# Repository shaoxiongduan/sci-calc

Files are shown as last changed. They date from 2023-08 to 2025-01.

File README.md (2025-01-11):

# sci-calc
<a href="https://github.com/shaoxiongduan/sci-calc/">
Repo Banner - Awesome Repo Template</a>

<p align="center">
  <b>SCI-CALC: A Multifunctional Scientific Calculator</b>

  <br>
    
  <a href="https://github.com/shaoxiongduan/sci-calc/fork">
    
  </a>
  
  <a href = "https://discord.gg/ZbaYb36wnn">

  </a>
</p> 

## Overview

The sci-calc (I know, really creative name) is a 4-in-1 device, packing a scientific calculator, a macropad/numpad, a handheld game console, and a development board all into one neat and sleek little device.

## Specs
- Powered by an ESP32 WROOM32 E [datasheet](www.espressif.com/sites/default/files/documentation/esp32-wroom-32e_esp32-wroom-32ue_datasheet_en.pdf)
- Switches: kailh v1 choc switches
- Screen: 256x64 monochrome oled (display driver: SSD1322)
- Usb to serial chip: CH340C [driver download](learn.sparkfun.com/tutorials/how-to-install-ch340-drivers/all)
- Battery: any lipo battery under 1000mah would be fine
- SD card support (must be in FAT32 format)

## Function Keys
- Switch layer key: switches between different layout configurations
  - hold to switch to next layer, release to go back (like shift)
  - double press to switch to next layer and lock (like caps lock)
- deg/rad: used in the calculator program to switch between degree mode and radian mode
- tab: also used in the calculator program, it's used to switch between the input box and the list of previous calculations
## UI
### Calculator
A calculator with a history clipboard that can do basic arithmetic (add, subtract, multiply, divide, powers), as well as trigonmetric functions, natural logrithms and exponents. Equation solver and derivative calculator will come soon.

when inputting expressions, switch layer is needed to move the cursor left or right, whereas in the history menu(and all of the other menus), holding switch layer is not necessary to use the arrow keys.
when in the history menu, use the arrow keys to navigate up/down, and press enter to copy the selected expression's answer to the input box.

[Video Demo (Outdated)](https://user-images.githubusercontent.com/46639847/219936733-cb611f87-4cae-4c7e-8eed-b2f6bcc909a7.mp4)

### Macropad

A bluetooth numpad that comes with 10 customizable macro keys, though all keys can be customized, only the 10 keys on the 2 rightmost rows can be displayed on the screen.
Macros and layers are very easy to create in code (see firmware), and I'm planning to make it possible to change and edit the layout via a text file in the SD card.

[Video Demo (Outdated)](https://user-images.githubusercontent.com/46639847/219937053-a5f0e39d-01d1-4069-9902-0d509ead685e.mp4)

### Programs

It is possible to upload your own code to the sci-calc by copying the .bin file that you compiled onto the SD card and creating a menu link to it in the main firmware code (see firmware), but this is kinda complicated and I'm trying to make it automatically create the link.
It's pretty easy to port code over to the sci-calc, just copy the Util.h, Util.cpp, Keyboard.h, Keyboard.cpp files over to your project and change the input checking functions.
Currently I've ported littlerookchess, spacetrash, snake, and tetris to it.

[Game Demo](docs/game_demo.md)

## Assembly Guide
[link](https://youtu.be/RY_riS_9hHA?si=YKYpsfk6U_JUeETe)

# Layouts

[Layouts](docs/layout.md)

# Troubleshooting
[Troubleshooting](docs/troubleshooting.md)

# Updating Software
[Updating Software](docs/updating_software.md)

# Setting up the Dev Environment
[Environment Setup](docs/environment_setup.md)

# Code Structure
[Code Structure and Walkthrough](docs/code_structure.md)

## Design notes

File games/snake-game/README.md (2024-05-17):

# Snake Game
Snake game running on esp32, displayed on SSD1306 controlled OLED, developed in Arduino.

Input pins can be changed in the main sketch file. It should be easily portable to other displays, just change the `renderer.cpp` and if needed adjust board size in `snake.h` too.

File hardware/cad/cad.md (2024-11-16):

# CAD Files

Full cad files can be viewed in [Onshape](https://cad.onshape.com/documents/948c55b28636babd8c20a62c/w/3db18c0d723d08fe7c6301bf/e/b61d2ec68282ba356d5c1233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)

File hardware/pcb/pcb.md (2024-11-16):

# PCB

The PCB was designed in EasyEDA.

[Link to EasyEDA](https://easyeda.com/editor#id=1234567890)

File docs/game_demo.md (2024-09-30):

# LittleRookChess


https://github.com/olikraus/u8g2/blob/master/sys/arduino/u8g2_page_buffer/LittleRookChess/LittleRookChess.ino
# Spacetrash


https://github.com/olikraus/u8g2/blob/master/sys/arduino/u8g2_page_buffer/SpaceTrash/SpaceTrash.ino
# Snake


https://github.com/norbertg1/Snake-game
# Tetris


https://github.com/Zimoslaw/TetriZimoslaw

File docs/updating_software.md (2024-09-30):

# Updating Software

## How It Works

The SCI-CALC can load external programs through a SD card.
Each time you load a program, the SCI-CALC writes the contents of the corresponding ```.bin``` file to the ESP32's ROM. For instance, when you load up Chess, it overwrites the existing ```main.bin``` in the ROM to ```chess.bin```. When you press esc to go back, The ```main.bin``` from the SD-card is written back into the ROM. This allows us to update programs without having to use an IDE to upload. The idea is to update the ```.bin``` file of the program in the SD-card, and then load it to the ESP32.

## Updating Software (New)
To update the software for your sci-calc, follow these steps:
1. Get the .bin file you want to update from the ```/bin``` folder.
2. Copy that file over to the microSD card, replacing the old .bin file you want to update.
3. Navigate to the settings menu and activate Update from SD.
4. After it is done writing to ROM it should be properly updated!

## Updating Software (Old)
If you do not see the Update From SD option in the settings menu, follow these steps:
1. Get the .bin file you want to update from the ```/bin``` folder from this repo.
2. Copy that file over to the microSD card, replacing the old .bin file you want to update.
3. Navigate to the programs menu and enter any one of them.
4. once the game is loaded press esc to load the updated main.bin file back to the ESP32.
5. After it is done writing to ROM it should be properly updated!

For updating the main software, do these steps with the ```main.bin``` file. Or you can just replace everything in the SD-card with the contents in the ```/bin``` folder.

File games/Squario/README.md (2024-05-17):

# Squario
### 5/25/16 Update:
Mushrooms picked up after becoming big Squario will fill him, up to 5 times  
Added underworld background and flipped the pipes to the ceiling

### 5/22/16 Update:
Added pipes to break up levels, levels get progressively longer  
Every other level has more of an underworld layout now  
Starmen and thunder bolts should only spawn towards the second half of each level  
Every 20 coins you earn an extra life  
Cleaned up hit detection  
Lots of random backend cleanup and other things I already forgot about

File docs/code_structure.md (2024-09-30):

# Code Structure

The source code for the sci-calc is structured as follows

Folders:
```
Animation
Calculator
Macropad
Stopwatch
UIElements
Utils
```
Files:
```
main.cpp/main.h
Sidebar.cpp/Sidebar.h
UIMain.cpp/UIMain.h
```

Now we will go into each part:
## Animation

The animation engine for the SCI-CALC works like this:

When you insert an animation, for instance this one:
```c++
insertAnimation(new Animation(subElements[i], BOUNCE, subElements[i] -> getX(), cnt * 12 + 12, 100));
```

The animation engine inserts the animation into the two pools depending on what you are animating (one for animating UIElements, one for animating variables)

```cpp
// An element might have multiple animations added to it at once, this mapping procedure makes sure that only the latest animation gets animated

void insertAnimation(Animation* animation) {
	if (animation -> getTargetElement() != nullptr) {
		animationsUI[animation -> getTargetElement()] = animation;
	}
	else {
		 nimationsInt[animation -> getTargetVal()] = animation;
	}
}
```

The animation scheduler then manages and updates the animations based on their duration and positions. This is done by calling their respective animation update functions based on their animation types.

See the code for more stuff.

## Calculator

The calculator folder contains all the regular and RPN calculator codes.

```Calculator.cpp/Calculator.h```: The UI Element for the scientific calculator. It wraps up the logic stuff to display the UI.

```Expression.cpp/Expression.h```
```Node.cpp/Node.h```
: This is where the calculations happen. The Expression class handles the tokenizing, tree-building, and evaluating of the expressions. The calculation module first takes in the input string from the Calculator UI's input box, and then parses it into mathematical tokens. It then uses the shunting-yard algorithm to build an abstract syntax tree (AST), which is used to do the actual calculations.

```ExpressionBlock.cpp/ExpressionBlock.h```
This is the UIElement for displaying the expressions in the history menu.

```CalculatorRPN.cpp/CalculatorRPN.h```
```EvaluatorRPN.cpp/EvaluatorRPN.h```
These classes are the UIElement components and the calculation part for the RPN calculator.

The RPN calculator has 5 registers: x, y, z, t, and a store register which is hidden. It supports basic stack manipulation operations like swap (x, y), push, and pop. I mainly referenced the HP RPN calculators and http://www.alcula.com/calculators/rpn/ when coding this.

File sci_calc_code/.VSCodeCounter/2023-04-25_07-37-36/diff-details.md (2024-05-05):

# Diff Details

Date : 2023-04-25 07:37:36

Directory /Users/shao/Documents/PlatformIO/Projects/230113-120228-esp32doit-devkit-v1

Total : 0 files,  0 codes, 0 comments, 0 blanks, all 0 lines

[Summary](results.md) / [Details](details.md) / [Diff Summary](diff.md) / Diff Details

## Files
| filename | language | code | comment | blank | total |
| :--- | :--- | ---: | ---: | ---: | ---: |

[Summary](results.md) / [Details](details.md) / [Diff Summary](diff.md) / Diff Details

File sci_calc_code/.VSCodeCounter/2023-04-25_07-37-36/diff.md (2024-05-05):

# Diff Summary

Date : 2023-04-25 07:37:36

Directory /Users/shao/Documents/PlatformIO/Projects/230113-120228-esp32doit-devkit-v1

Total : 0 files,  0 codes, 0 comments, 0 blanks, all 0 lines

[Summary](results.md) / [Details](details.md) / Diff Summary / [Diff Details](diff-details.md)

## Languages
| language | files | code | comment | blank | total |
| :--- | ---: | ---: | ---: | ---: | ---: |

## Directories
| path | files | code | comment | blank | total |
| :--- | ---: | ---: | ---: | ---: | ---: |

[Summary](results.md) / [Details](details.md) / Diff Summary / [Diff Details](diff-details.md)

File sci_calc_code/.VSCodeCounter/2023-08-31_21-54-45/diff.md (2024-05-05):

# Diff Summary

Date : 2023-08-31 21:54:45

Directory /Users/shao/Documents/PlatformIO/Projects/230113-120228-esp32doit-devkit-v1

Total : 24 files,  401 codes, 41 comments, 80 blanks, all 522 lines

[Summary](results.md) / [Details](details.md) / Diff Summary / [Diff Details](diff-details.md)

## Languages
| language | files | code | comment | blank | total |
| :--- | ---: | ---: | ---: | ---: | ---: |
| C++ | 23 | 402 | 41 | 81 | 524 |
| Ini | 1 | -1 | 0 | -1 | -2 |

## Directories
| path | files | code | comment | blank | total |
| :--- | ---: | ---: | ---: | ---: | ---: |
| . | 24 | 401 | 41 | 80 | 522 |
| . (Files) | 1 | -1 | 0 | -1 | -2 |
| src | 23 | 402 | 41 | 81 | 524 |

[Summary](results.md) / [Details](details.md) / Diff Summary / [Diff Details](diff-details.md)

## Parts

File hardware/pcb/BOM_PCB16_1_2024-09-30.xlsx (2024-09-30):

No. | Quantity | Comment | Designator | Footprint | Value | Manufacturer Part | Manufacturer | Supplier Part | Supplier
1 | 26 | 2.54-1*1P针 | 5,13,14,15,16,17,18,19,21,22,23,25,26,27,32,33,34,35,36,39,GND,GND,RX,TX,VCC,VCC | HDR-TH_1P-P2.54-V-M |  | 2.54-1*1P针 | BOOMELE(博穆精密) | C81276 | LCSC
2 | 2 | TS-1088-AR02016 | BOOT,EN | SW-SMD_L4.0-W2.9-LS5.0 |  | TS-1088-AR02016 | XUNPU(讯普) | C720477 | LCSC
3 | 2 | 10uF | C1,C6 | C0603 | 10uF | CL10A106KP8NNNC | SAMSUNG(三星) | C19702 | LCSC
4 | 5 | 0.1uF | C2,C4,C5,C7,C8 | C0603 | 0.1uF | CC0603KRX7R9BB104 | YAGEO(国巨) | C14663 | LCSC
5 | 1 | 10uF | C3 | C0805 | 10uF | CL21A106KAYNNNE | SAMSUNG(三星) | C15850 | LCSC
6 | 2 | 22uF | C10,C11 | C0805 | 22uF | CL21A226MAQNNNE | SAMSUNG(三星) | C45783 | LCSC
7 | 1 | TF-01A | CARD1 | TF-SMD_TF-02 |  | TF-01A | Yuandi(台湾元迪) | C2889258 | LCSC
8 | 30 | 1N4148W | D1,D2,D3,D4,D5,D6,D7,D8,D9,D10,D11,D12,D13,D14,D15,D16,D17,D18,D19,D20,D21,D22,D23,D24,D25,D26,D27,D28,D29,D30 | SOD-123F_L2.7-W1.6-LS3.8-RD |  | 1N4148W | ST(先科) | C81598 | LCSC
9 | 1 | SS34 | D32 | DO-214AC_L4.3-W2.7-LS5.3-RD |  | SS34 | MDD | C8678 | LCSC
10 | 1 | TPD4E1U06DCKR | D33 | SC-70-6_L2.2-W1.3-P0.65-LS2.1-BL |  | TPD4E1U06DCKR | TI(德州仪器) | C194628 | LCSC
11 | 1 | 470nH | L2 | IND-SMD_L5.7-W5.4 | 470nH | MHCI05030-R47M-R8 | chilisin(奇力新) | C329374 | LCSC
12 | 2 | 19-217/R6C-AL1M2VY/3T | LED1,PWR | LED0603-R-RD |  | 19-217/R6C-AL1M2VY/3T | EVERLIGHT(台湾亿光) | C72044 | LCSC
13 | 1 | 19-217/GHC-YR1S2/3T | LED2 | LED0603-R-RD |  | 19-217/GHC-YR1S2/3T | EVERLIGHT(台湾亿光) | C72043 | LCSC
14 | 1 | FS8205 | Q1 | SOT-23-6_L2.9-W1.6-P0.95-LS2.8-BR |  | FS8205 | FORTUNE(台湾富晶) | C32254 | LCSC
15 | 1 | AO3401A | Q2 | SOT-23_L2.9-W1.3-P1.90-LS2.4-BR |  | AO3401A | AOS | C15127 | LCSC
16 | 2 | S8050 | Q3,Q4 | SOT-23-3_L2.9-W1.3-P1.90-LS2.4-BR |  | S8050 | 星海 | C2992076 | LCSC
17 | 3 | 1kΩ | R1,R2,R13 | R0603 | 1kΩ | RC0603FR-071KL | YAGEO(国巨) | C22548 | LCSC
18 | 1 | 5kΩ | R3 | R0603 | 5kΩ | AR03BTCX5001 | Viking(光颉) | C2828621 | LCSC
19 | 3 | 100Ω | R4,R10,R11 | R0603 | 100Ω | RC0603FR-07100RL | YAGEO(国巨) | C105588 | LCSC
20 | 1 | 2kΩ | R5 | R0603 | 2kΩ | RC0603FR-072KL | YAGEO(国巨) | C105576 | LCSC
21 | 7 | 10kΩ | R6,R7,R8,R9,R14,R19,R22 | R0603 | 10kΩ | RC0603FR-0710KL | YAGEO(国巨) | C98220 | LCSC
22 | 8 | 10kΩ | R12,R15,R16,R23,R24,R25,R26,R27 | R0603 | 10kΩ | TR0603B10K0P0525Z | EVER OHMS(天二科技) | C188363 | LCSC
23 | 2 | 5.1kΩ | R17,R18 | R0603 | 5.1kΩ | 0603WAF5101T5E | UNI-ROYAL(厚声) | C23186 | LCSC
24 | 1 | 91kΩ | R20 | R0603 | 91kΩ | 0603WAF9102T5E | UNI-ROYAL(厚声) | C23265 | LCSC
25 | 1 | 511kΩ | R21 | R0603 | 511kΩ | 0603WAF5113T5E | UNI-ROYAL(厚声) | C23194 | LCSC
26 | 2 | 100k | R28,R29 | R0603 |  | 100k |  | C9900012835 | LCSC
27 | 30 | CPG135001D01 | SW1,SW2,SW3,SW4,SW5,SW6,SW7,SW8,SW9,SW10,SW11,SW12,SW13,SW14,SW15,SW16,SW17,SW18,SW19,SW20,SW21,SW22,SW23,SW24,SW25,SW26,SW27,SW28,SW29,SW30 | KEY-TH_CPG135001D0X |  | CPG135001D01 | Kailh(凯华) | C400229 | LCSC
28 | 1 | SK12D07VG4 | SW35 | SW-TH_SK12D07VG4 |  | SK12D07VG4 | SHOU HAN(首韩) | C393937 | LCSC
29 | 1 | 4056 | U1 | ESOP-8_L4.9-W3.9-P1.27-LS6.0-BL-EP |  | 4056 | RONGHE(融和) | C392766 | LCSC
30 | 1 | DW01 | U2 | SOT-23-6_L2.9-W1.6-P0.95-LS2.8-BR |  | DW01 | PJSEMI(平晶微) | C686633 | LCSC
31 | 1 | ESP32-WROOM-32E-H4 | U4 | WIFI-SMD_ESP32-WROOM-32E |  | ESP32-WROOM-32E-H4 | ESPRESSIF(乐鑫) | C3013935 | LCSC
32 | 1 | oled | U5 | oled3.1
33 | 1 | CH340C | U6 | SOP-16_L10.0-W3.9-P1.27-LS6.0-BL |  | CH340C | WCH(南京沁恒) | C84681 | LCSC
34 | 1 | TPS63802DLAR | U7 | VSON-10_L3.0-W2.0-P0.50-TL |  | TPS63802DLAR | TI(德州仪器) | C2845237 | LCSC
35 | 1 | TYPE-C-31-M-12 | USBC1 | USB-C_SMD-TYPE-C-31-M-12 |  | TYPE-C-31-M-12 | 韩国韩荣 | C165948 | LCSC

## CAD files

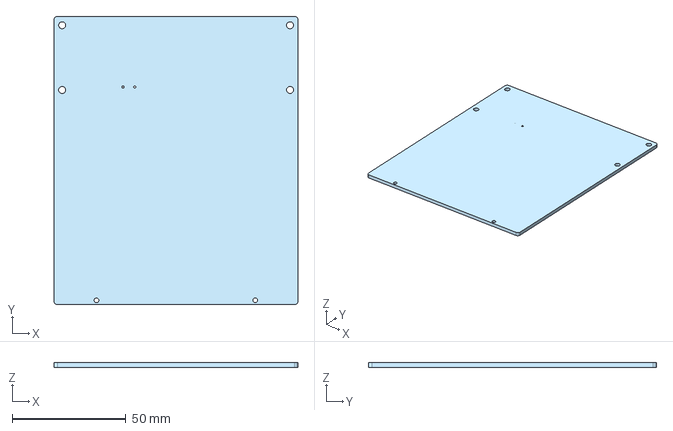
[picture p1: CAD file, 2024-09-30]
hardware/cad/Part Studio 1 - Base Plate.step
107.5 x 127.0 x 2.00 mm

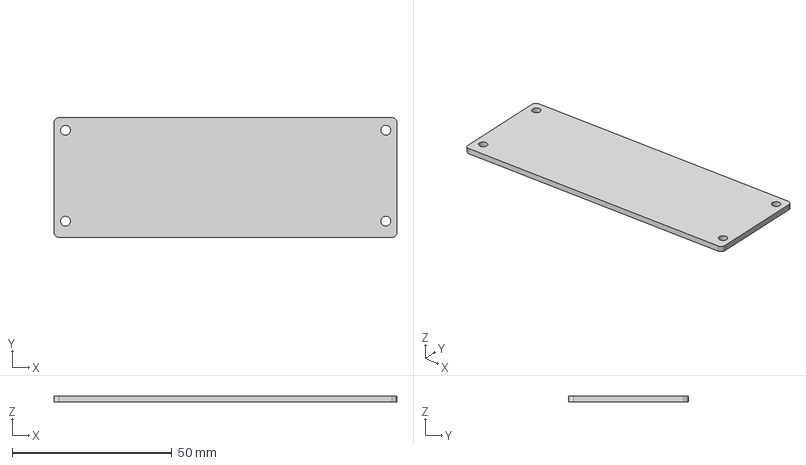
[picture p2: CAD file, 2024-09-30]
hardware/cad/Part Studio 1 - Top Plate.step
107.5 x 37.5 x 2.00 mm

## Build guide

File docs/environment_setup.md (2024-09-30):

# Setting up the Dev Environment

## Arduino IDE
1. Install the Arduino IDE: https://www.arduino.cc/en/software
2. Install the drivers for the CH340 chip: https://learn.sparkfun.com/tutorials/how-to-install-ch340-drivers/all
3. Set up the Arduino IDE by following the steps for a regular ESP32 dev board: https://randomnerdtutorials.com/installing-esp32-arduino-ide-2-0/ (You don't have to do the test installation steps and the steps after)

4. Now you can start programming the SCI-CALC! When uploading, use the ESP32 Dev Board option for the board type.

# VSCode + PlatformIO

1. Install VSCode: https://code.visualstudio.com/
2. After installing VSCode, navigate to the extension tab on the left and install the PlatformIO extension: 
3. Clone this Github repo and open the ```sci_calc_code``` folder in VSCode with PlatformIO.
4. Navigate to the ```src``` folder to view and modify the source code. When done modifying, upload the code using the Upload button at the bottom.

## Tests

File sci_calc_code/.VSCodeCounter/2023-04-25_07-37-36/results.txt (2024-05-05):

Date : 2023-04-25 07:37:36
Directory : /Users/shao/Documents/PlatformIO/Projects/230113-120228-esp32doit-devkit-v1
Total : 54 files,  3394 codes, 207 comments, 806 blanks, all 4407 lines

Languages
+----------+------------+------------+------------+------------+------------+
| language | files      | code       | comment    | blank      | total      |
+----------+------------+------------+------------+------------+------------+
| C++      |         53 |      3,380 |        198 |        803 |      4,381 |
| Ini      |          1 |         14 |          9 |          3 |         26 |
+----------+------------+------------+------------+------------+------------+

Directories
+-----------------------------------------------------------------------------------------------------+------------+------------+------------+------------+------------+
| path                                                                                                | files      | code       | comment    | blank      | total      |
+-----------------------------------------------------------------------------------------------------+------------+------------+------------+------------+------------+
| .                                                                                                   |         54 |      3,394 |        207 |        806 |      4,407 |
| . (Files)                                                                                           |          1 |         14 |          9 |          3 |         26 |
| src                                                                                                 |         53 |      3,380 |        198 |        803 |      4,381 |
+-----------------------------------------------------------------------------------------------------+------------+------------+------------+------------+------------+

Files
+-----------------------------------------------------------------------------------------------------+----------+------------+------------+------------+------------+
| filename                                                                                            | language | code       | comment    | blank      | total      |
+-----------------------------------------------------------------------------------------------------+----------+------------+------------+------------+------------+
| /Users/shao/Documents/PlatformIO/Projects/230113-120228-esp32doit-devkit-v1/platformio.ini          | Ini      |         14 |          9 |          3 |         26 |
| /Users/shao/Documents/PlatformIO/Projects/230113-120228-esp32doit-devkit-v1/src/Animation.cpp       | C++      |        254 |         34 |         45 |        333 |
| /Users/shao/Documents/PlatformIO/Projects/230113-120228-esp32doit-devkit-v1/src/Animation.h         | C++      |         38 |          2 |         22 |         62 |
| /Users/shao/Documents/PlatformIO/Projects/230113-120228-esp32doit-devkit-v1/src/BinLink.cpp         | C++      |         12 |          0 |          6 |         18 |
| /Users/shao/Documents/PlatformIO/Projects/230113-120228-esp32doit-devkit-v1/src/BinLink.h           | C++      |         14 |          0 |          7 |         21 |
| /Users/shao/Documents/PlatformIO/Projects/230113-120228-esp32doit-devkit-v1/src/Box.cpp             | C++      |          7 |          0 |          3 |         10 |
| /Users/shao/Documents/PlatformIO/Projects/230113-120228-esp32doit-devkit-v1/src/Box.h               | C++      |         10 |          0 |          6 |         16 |
| /Users/shao/Documents/PlatformIO/Projects/230113-120228-esp32doit-devkit-v1/src/Calculator.cpp      | C++      |         91 |          7 |         11 |        109 |
| /Users/shao/Documents/PlatformIO/Projects/230113-120228-esp32doit-devkit-v1/src/Calculator.h        | C++      |         24 |          1 |          8 |         33 |
| /Users/shao/Documents/PlatformIO/Projects/230113-120228-esp32doit-devkit-v1/src/Checkbox.cpp        | C++      |         42 |          0 |          8 |         50 |
| /Users/shao/Documents/PlatformIO/Projects/230113-120228-esp32doit-devkit-v1/src/Checkbox.h          | C++      |         20 |          0 |          7 |         27 |
| /Users/shao/Documents/PlatformIO/Projects/230113-120228-esp32doit-devkit-v1/src/ChineseText.cpp     | C++      |        234 |          1 |         16 |        251 |
| /Users/shao/Documents/PlatformIO/Projects/230113-120228-esp32doit-devkit-v1/src/ChineseText.h       | C++      |         16 |          0 |          6 |         22 |
| /Users/shao/Documents/PlatformIO/Projects/230113-120228-esp32doit-devkit-v1/src/Cursor.cpp          | C++      |         35 |          0 |         10 |         45 |
| /Users/shao/Documents/PlatformIO/Projects/230113-120228-esp32doit-devkit-v1/src/Cursor.h            | C++      |         18 |          0 |         12 |         30 |
| /Users/shao/Documents/PlatformIO/Projects/230113-120228-esp32doit-devkit-v1/src/Expression.cpp      | C++      |        386 |         21 |         42 |        449 |
| /Users/shao/Documents/PlatformIO/Projects/230113-120228-esp32doit-devkit-v1/src/Expression.h        | C++      |         34 |          0 |         28 |         62 |
| /Users/shao/Documents/PlatformIO/Projects/230113-120228-esp32doit-devkit-v1/src/ExpressionBlock.cpp | C++      |         26 |          0 |          6 |         32 |
| /Users/shao/Documents/PlatformIO/Projects/230113-120228-esp32doit-devkit-v1/src/ExpressionBlock.h   | C++      |         23 |          0 |          8 |         31 |
| /Users/shao/Documents/PlatformIO/Projects/230113-120228-esp32doit-devkit-v1/src/IOLogger.cpp        | C++      |          0 |          0 |          1 |          1 |
| /Users/shao/Documents/PlatformIO/Projects/230113-120228-esp32doit-devkit-v1/src/IOLogger.h          | C++      |         10 |          0 |          4 |         14 |
| /Users/shao/Documents/PlatformIO/Projects/230113-120228-esp32doit-devkit-v1/src/InputBox.cpp        | C++      |        150 |          7 |         27 |        184 |
| /Users/shao/Documents/PlatformIO/Projects/230113-120228-esp32doit-devkit-v1/src/InputBox.h          | C++      |         33 |          0 |         20 |         53 |
| /Users/shao/Documents/PlatformIO/Projects/230113-120228-esp32doit-devkit-v1/src/Keyboard.cpp        | C++      |        154 |          6 |         22 |        182 |
| /Users/shao/Documents/PlatformIO/Projects/230113-120228-esp32doit-devkit-v1/src/Keyboard.h          | C++      |         36 |          0 |         26 |         62 |
| /Users/shao/Documents/PlatformIO/Projects/230113-120228-esp32doit-devkit-v1/src/ListSelector.cpp    | C++      |          8 |          0 |          3 |         11 |
| /Users/shao/Documents/PlatformIO/Projects/230113-120228-esp32doit-devkit-v1/src/ListSelector.h      | C++      |         24 |          0 |          5 |         29 |
| /Users/shao/Documents/PlatformIO/Projects/230113-120228-esp32doit-devkit-v1/src/Macropad.cpp        | C++      |        170 |         11 |         24 |        205 |
| /Users/shao/Documents/PlatformIO/Projects/230113-120228-esp32doit-devkit-v1/src/Macropad.h          | C++      |         40 |          0 |         20 |         60 |
| /Users/shao/Documents/PlatformIO/Projects/230113-120228-esp32doit-devkit-v1/src/MacropadUI.cpp      | C++      |         18 |          1 |          5 |         24 |
| /Users/shao/Documents/PlatformIO/Projects/230113-120228-esp32doit-devkit-v1/src/MacropadUI.h        | C++      |         15 |          0 |          7 |         22 |
| /Users/shao/Documents/PlatformIO/Projects/230113-120228-esp32doit-devkit-v1/src/Menu.cpp            | C++      |        193 |         16 |         30 |        239 |
| /Users/shao/Documents/PlatformIO/Projects/230113-120228-esp32doit-devkit-v1/src/Menu.h              | C++      |         35 |          1 |         23 |         59 |
| /Users/shao/Documents/PlatformIO/Projects/230113-120228-esp32doit-devkit-v1/src/Node.cpp            | C++      |        125 |         14 |         28 |        167 |
| /Users/shao/Documents/PlatformIO/Projects/230113-120228-esp32doit-devkit-v1/src/Node.h              | C++      |         39 |          0 |         28 |         67 |
| /Users/shao/Documents/PlatformIO/Projects/230113-120228-esp32doit-devkit-v1/src/ProgressBar.cpp     | C++      |         20 |          1 |          5 |         26 |
| /Users/shao/Documents/PlatformIO/Projects/230113-120228-esp32doit-devkit-v1/src/ProgressBar.h       | C++      |         13 |          1 |          6 |         20 |
| /Users/shao/Documents/PlatformIO/Projects/230113-120228-esp32doit-devkit-v1/src/Sidebar.cpp         | C++      |         11 |          0 |          2 |         13 |
| /Users/shao/Documents/PlatformIO/Projects/230113-120228-esp32doit-devkit-v1/src/Sidebar.h           | C++      |          5 |          0 |          3 |          8 |
| /Users/shao/Documents/PlatformIO/Projects/230113-120228-esp32doit-devkit-v1/src/Slider.cpp          | C++      |         83 |          7 |         13 |        103 |
| /Users/shao/Documents/PlatformIO/Projects/230113-120228-esp32doit-devkit-v1/src/Slider.h            | C++      |         27 |          0 |          6 |         33 |
| /Users/shao/Documents/PlatformIO/Projects/230113-120228-esp32doit-devkit-v1/src/Stopwatch.cpp       | C++      |         49 |          0 |         14 |         63 |
| /Users/shao/Documents/PlatformIO/Projects/230113-120228-esp32doit-devkit-v1/src/Stopwatch.h         | C++      |         21 |          1 |         14 |         36 |
| /Users/shao/Documents/PlatformIO/Projects/230113-120228-esp32doit-devkit-v1/src/StopwatchUI.cpp     | C++      |         55 |          1 |          9 |         65 |
| /Users/shao/Documents/PlatformIO/Projects/230113-120228-esp32doit-devkit-v1/src/StopwatchUI.h       | C++      |         18 |          0 |          8 |         26 |
| /Users/shao/Documents/PlatformIO/Projects/230113-120228-esp32doit-devkit-v1/src/Text.cpp            | C++      |         31 |          0 |         12 |         43 |
| /Users/shao/Documents/PlatformIO/Projects/230113-120228-esp32doit-devkit-v1/src/Text.h              | C++      |         18 |          0 |          6 |         24 |
| /Users/shao/Documents/PlatformIO/Projects/230113-120228-esp32doit-devkit-v1/src/UIElement.cpp       | C++      |        109 |          1 |         36 |        146 |
| /Users/shao/Documents/PlatformIO/Projects/230113-120228-esp32doit-devkit-v1/src/UIElement.h         | C++      |         48 |          0 |         35 |         83 |
| /Users/shao/Documents/PlatformIO/Projects/230113-120228-esp32doit-devkit-v1/src/UIMain.cpp          | C++      |        145 |          1 |         31 |        177 |
| /Users/shao/Documents/PlatformIO/Projects/230113-120228-esp32doit-devkit-v1/src/UIMain.h            | C++      |         33 |          0 |          7 |         40 |
| /Users/shao/Documents/PlatformIO/Projects/230113-120228-esp32doit-devkit-v1/src/Util.cpp            | C++      |        227 |         46 |         34 |        307 |
| /Users/shao/Documents/PlatformIO/Projects/230113-120228-esp32doit-devkit-v1/src/Util.h              | C++      |         89 |          2 |         20 |        111 |
| /Users/shao/Documents/PlatformIO/Projects/230113-120228-esp32doit-devkit-v1/src/main.cpp            | C++      |         44 |         15 |         18 |         77 |
| Total                                                                                               |          |      3,394 |        207 |        806 |      4,407 |
+-----------------------------------------------------------------------------------------------------+----------+------------+------------+------------+------------+

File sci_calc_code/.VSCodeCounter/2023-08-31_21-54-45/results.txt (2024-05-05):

Date : 2023-08-31 21:54:45
Directory : /Users/shao/Documents/PlatformIO/Projects/230113-120228-esp32doit-devkit-v1
Total : 56 files,  3795 codes, 248 comments, 886 blanks, all 4929 lines

Languages
+----------+------------+------------+------------+------------+------------+
| language | files      | code       | comment    | blank      | total      |
+----------+------------+------------+------------+------------+------------+
| C++      |         55 |      3,782 |        239 |        884 |      4,905 |
| Ini      |          1 |         13 |          9 |          2 |         24 |
+----------+------------+------------+------------+------------+------------+

Directories
+-----------------------------------------------------------------------------------------------------+------------+------------+------------+------------+------------+
| path                                                                                                | files      | code       | comment    | blank      | total      |
+-----------------------------------------------------------------------------------------------------+------------+------------+------------+------------+------------+
| .                                                                                                   |         56 |      3,795 |        248 |        886 |      4,929 |
| . (Files)                                                                                           |          1 |         13 |          9 |          2 |         24 |
| src                                                                                                 |         55 |      3,782 |        239 |        884 |      4,905 |
+-----------------------------------------------------------------------------------------------------+------------+------------+------------+------------+------------+

Files
+-----------------------------------------------------------------------------------------------------+----------+------------+------------+------------+------------+
| filename                                                                                            | language | code       | comment    | blank      | total      |
+-----------------------------------------------------------------------------------------------------+----------+------------+------------+------------+------------+
| /Users/shao/Documents/PlatformIO/Projects/230113-120228-esp32doit-devkit-v1/platformio.ini          | Ini      |         13 |          9 |          2 |         24 |
| /Users/shao/Documents/PlatformIO/Projects/230113-120228-esp32doit-devkit-v1/src/Animation.cpp       | C++      |        403 |         19 |         73 |        495 |
| /Users/shao/Documents/PlatformIO/Projects/230113-120228-esp32doit-devkit-v1/src/Animation.h         | C++      |         52 |          0 |         25 |         77 |
| /Users/shao/Documents/PlatformIO/Projects/230113-120228-esp32doit-devkit-v1/src/BinLink.cpp         | C++      |         12 |          0 |          6 |         18 |
| /Users/shao/Documents/PlatformIO/Projects/230113-120228-esp32doit-devkit-v1/src/BinLink.h           | C++      |         14 |          0 |          7 |         21 |
| /Users/shao/Documents/PlatformIO/Projects/230113-120228-esp32doit-devkit-v1/src/Box.cpp             | C++      |          7 |          0 |          3 |         10 |
| /Users/shao/Documents/PlatformIO/Projects/230113-120228-esp32doit-devkit-v1/src/Box.h               | C++      |         10 |          0 |          6 |         16 |
| /Users/shao/Documents/PlatformIO/Projects/230113-120228-esp32doit-devkit-v1/src/Calculator.cpp      | C++      |        107 |         10 |         13 |        130 |
| /Users/shao/Documents/PlatformIO/Projects/230113-120228-esp32doit-devkit-v1/src/Calculator.h        | C++      |         24 |          1 |          8 |         33 |
| /Users/shao/Documents/PlatformIO/Projects/230113-120228-esp32doit-devkit-v1/src/Checkbox.cpp        | C++      |         45 |          0 |          8 |         53 |
| /Users/shao/Documents/PlatformIO/Projects/230113-120228-esp32doit-devkit-v1/src/Checkbox.h          | C++      |         20 |          0 |          7 |         27 |
| /Users/shao/Documents/PlatformIO/Projects/230113-120228-esp32doit-devkit-v1/src/ChineseText.cpp     | C++      |        234 |          1 |         16 |        251 |
| /Users/shao/Documents/PlatformIO/Projects/230113-120228-esp32doit-devkit-v1/src/ChineseText.h       | C++      |         16 |          0 |          6 |         22 |
| /Users/shao/Documents/PlatformIO/Projects/230113-120228-esp32doit-devkit-v1/src/Cursor.cpp          | C++      |         46 |          0 |         12 |         58 |
| /Users/shao/Documents/PlatformIO/Projects/230113-120228-esp32doit-devkit-v1/src/Cursor.h            | C++      |         19 |          0 |         11 |         30 |
| /Users/shao/Documents/PlatformIO/Projects/230113-120228-esp32doit-devkit-v1/src/Expression.cpp      | C++      |        386 |         21 |         42 |        449 |
| /Users/shao/Documents/PlatformIO/Projects/230113-120228-esp32doit-devkit-v1/src/Expression.h        | C++      |         34 |          0 |         28 |         62 |
| /Users/shao/Documents/PlatformIO/Projects/230113-120228-esp32doit-devkit-v1/src/ExpressionBlock.cpp | C++      |         27 |          0 |          6 |         33 |
| /Users/shao/Documents/PlatformIO/Projects/230113-120228-esp32doit-devkit-v1/src/ExpressionBlock.h   | C++      |         23 |          0 |          8 |         31 |
| /Users/shao/Documents/PlatformIO/Projects/230113-120228-esp32doit-devkit-v1/src/Funstuff.cpp        | C++      |         32 |         42 |          6 |         80 |
| /Users/shao/Documents/PlatformIO/Projects/230113-120228-esp32doit-devkit-v1/src/Funstuff.h          | C++      |         20 |          0 |          9 |         29 |
| /Users/shao/Documents/PlatformIO/Projects/230113-120228-esp32doit-devkit-v1/src/IOLogger.cpp        | C++      |          0 |          0 |          1 |          1 |
| /Users/shao/Documents/PlatformIO/Projects/230113-120228-esp32doit-devkit-v1/src/IOLogger.h          | C++      |         10 |          0 |          4 |         14 |
| /Users/shao/Documents/PlatformIO/Projects/230113-120228-esp32doit-devkit-v1/src/InputBox.cpp        | C++      |        151 |          8 |         27 |        186 |
| /Users/shao/Documents/PlatformIO/Projects/230113-120228-esp32doit-devkit-v1/src/InputBox.h          | C++      |         33 |          0 |         20 |         53 |
| /Users/shao/Documents/PlatformIO/Projects/230113-120228-esp32doit-devkit-v1/src/Keyboard.cpp        | C++      |        154 |          6 |         22 |        182 |
| /Users/shao/Documents/PlatformIO/Projects/230113-120228-esp32doit-devkit-v1/src/Keyboard.h          | C++      |         36 |          0 |         26 |         62 |
| /Users/shao/Documents/PlatformIO/Projects/230113-120228-esp32doit-devkit-v1/src/ListSelector.cpp    | C++      |          8 |          0 |          3 |         11 |
| /Users/shao/Documents/PlatformIO/Projects/230113-120228-esp32doit-devkit-v1/src/ListSelector.h      | C++      |         24 |          0 |          5 |         29 |
| /Users/shao/Documents/PlatformIO/Projects/230113-120228-esp32doit-devkit-v1/src/Macropad.cpp        | C++      |        173 |         11 |         23 |        207 |
| /Users/shao/Documents/PlatformIO/Projects/230113-120228-esp32doit-devkit-v1/src/Macropad.h          | C++      |         40 |          0 |         20 |         60 |
| /Users/shao/Documents/PlatformIO/Projects/230113-120228-esp32doit-devkit-v1/src/MacropadUI.cpp      | C++      |         19 |          1 |          5 |         25 |
| /Users/shao/Documents/PlatformIO/Projects/230113-120228-esp32doit-devkit-v1/src/MacropadUI.h        | C++      |         15 |          0 |          7 |         22 |
| /Users/shao/Documents/PlatformIO/Projects/230113-120228-esp32doit-devkit-v1/src/Menu.cpp            | C++      |        238 |         25 |         38 |        301 |
| /Users/shao/Documents/PlatformIO/Projects/230113-120228-esp32doit-devkit-v1/src/Menu.h              | C++      |         38 |          1 |         25 |         64 |
| /Users/shao/Documents/PlatformIO/Projects/230113-120228-esp32doit-devkit-v1/src/Node.cpp            | C++      |        125 |         14 |         28 |        167 |
| /Users/shao/Documents/PlatformIO/Projects/230113-120228-esp32doit-devkit-v1/src/Node.h              | C++      |         39 |          0 |         28 |         67 |
| /Users/shao/Documents/PlatformIO/Projects/230113-120228-esp32doit-devkit-v1/src/ProgressBar.cpp     | C++      |         20 |          1 |          5 |         26 |
| /Users/shao/Documents/PlatformIO/Projects/230113-120228-esp32doit-devkit-v1/src/ProgressBar.h       | C++      |         13 |          1 |          6 |         20 |
| /Users/shao/Documents/PlatformIO/Projects/230113-120228-esp32doit-devkit-v1/src/Sidebar.cpp         | C++      |         13 |          0 |          2 |         15 |
| /Users/shao/Documents/PlatformIO/Projects/230113-120228-esp32doit-devkit-v1/src/Sidebar.h           | C++      |          5 |          0 |          3 |          8 |
| /Users/shao/Documents/PlatformIO/Projects/230113-120228-esp32doit-devkit-v1/src/Slider.cpp          | C++      |         83 |          7 |         13 |        103 |
| /Users/shao/Documents/PlatformIO/Projects/230113-120228-esp32doit-devkit-v1/src/Slider.h            | C++      |         27 |          0 |          6 |         33 |
| /Users/shao/Documents/PlatformIO/Projects/230113-120228-esp32doit-devkit-v1/src/Stopwatch.cpp       | C++      |         49 |          0 |         14 |         63 |
| /Users/shao/Documents/PlatformIO/Projects/230113-120228-esp32doit-devkit-v1/src/Stopwatch.h         | C++      |         21 |          1 |         14 |         36 |
| /Users/shao/Documents/PlatformIO/Projects/230113-120228-esp32doit-devkit-v1/src/StopwatchUI.cpp     | C++      |         64 |          2 |          9 |         75 |
| /Users/shao/Documents/PlatformIO/Projects/230113-120228-esp32doit-devkit-v1/src/StopwatchUI.h       | C++      |         18 |          0 |          8 |         26 |
| /Users/shao/Documents/PlatformIO/Projects/230113-120228-esp32doit-devkit-v1/src/Text.cpp            | C++      |         31 |          0 |         12 |         43 |
| /Users/shao/Documents/PlatformIO/Projects/230113-120228-esp32doit-devkit-v1/src/Text.h              | C++      |         18 |          0 |          6 |         24 |
| /Users/shao/Documents/PlatformIO/Projects/230113-120228-esp32doit-devkit-v1/src/UIElement.cpp       | C++      |        151 |          1 |         41 |        193 |
| /Users/shao/Documents/PlatformIO/Projects/230113-120228-esp32doit-devkit-v1/src/UIElement.h         | C++      |         54 |          0 |         41 |         95 |
| /Users/shao/Documents/PlatformIO/Projects/230113-120228-esp32doit-devkit-v1/src/UIMain.cpp          | C++      |        164 |          1 |         32 |        197 |
| /Users/shao/Documents/PlatformIO/Projects/230113-120228-esp32doit-devkit-v1/src/UIMain.h            | C++      |         34 |          0 |          7 |         41 |
| /Users/shao/Documents/PlatformIO/Projects/230113-120228-esp32doit-devkit-v1/src/Util.cpp            | C++      |        243 |         46 |         39 |        328 |
| /Users/shao/Documents/PlatformIO/Projects/230113-120228-esp32doit-devkit-v1/src/Util.h              | C++      |         94 |          3 |         22 |        119 |
| /Users/shao/Documents/PlatformIO/Projects/230113-120228-esp32doit-devkit-v1/src/main.cpp            | C++      |         46 |         16 |         22 |         84 |
| Total                                                                                               |          |      3,795 |        248 |        886 |      4,929 |
+-----------------------------------------------------------------------------------------------------+----------+------------+------------+------------+------------+

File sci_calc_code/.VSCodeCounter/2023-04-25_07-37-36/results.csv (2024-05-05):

filename | "language" | "C++" | "Ini" | "comment" | "blank" | "total"
/Users/shao/Documents/PlatformIO/Projects/230113-120228-esp32doit-devkit-v1/platformio.ini | "Ini" | 0 | 14 | 9 | 3 | 26
/Users/shao/Documents/PlatformIO/Projects/230113-120228-esp32doit-devkit-v1/src/Animation.cpp | "C++" | 254 | 0 | 34 | 45 | 333
/Users/shao/Documents/PlatformIO/Projects/230113-120228-esp32doit-devkit-v1/src/Animation.h | "C++" | 38 | 0 | 2 | 22 | 62
/Users/shao/Documents/PlatformIO/Projects/230113-120228-esp32doit-devkit-v1/src/BinLink.cpp | "C++" | 12 | 0 | 0 | 6 | 18
/Users/shao/Documents/PlatformIO/Projects/230113-120228-esp32doit-devkit-v1/src/BinLink.h | "C++" | 14 | 0 | 0 | 7 | 21
/Users/shao/Documents/PlatformIO/Projects/230113-120228-esp32doit-devkit-v1/src/Box.cpp | "C++" | 7 | 0 | 0 | 3 | 10
/Users/shao/Documents/PlatformIO/Projects/230113-120228-esp32doit-devkit-v1/src/Box.h | "C++" | 10 | 0 | 0 | 6 | 16
/Users/shao/Documents/PlatformIO/Projects/230113-120228-esp32doit-devkit-v1/src/Calculator.cpp | "C++" | 91 | 0 | 7 | 11 | 109
/Users/shao/Documents/PlatformIO/Projects/230113-120228-esp32doit-devkit-v1/src/Calculator.h | "C++" | 24 | 0 | 1 | 8 | 33
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

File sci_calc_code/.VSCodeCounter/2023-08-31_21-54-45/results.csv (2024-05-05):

filename | "language" | "Ini" | "C++" | "comment" | "blank" | "total"
/Users/shao/Documents/PlatformIO/Projects/230113-120228-esp32doit-devkit-v1/platformio.ini | "Ini" | 13 | 0 | 9 | 2 | 24
/Users/shao/Documents/PlatformIO/Projects/230113-120228-esp32doit-devkit-v1/src/Animation.cpp | "C++" | 0 | 403 | 19 | 73 | 495
/Users/shao/Documents/PlatformIO/Projects/230113-120228-esp32doit-devkit-v1/src/Animation.h | "C++" | 0 | 52 | 0 | 25 | 77
/Users/shao/Documents/PlatformIO/Projects/230113-120228-esp32doit-devkit-v1/src/BinLink.cpp | "C++" | 0 | 12 | 0 | 6 | 18
/Users/shao/Documents/PlatformIO/Projects/230113-120228-esp32doit-devkit-v1/src/BinLink.h | "C++" | 0 | 14 | 0 | 7 | 21
/Users/shao/Documents/PlatformIO/Projects/230113-120228-esp32doit-devkit-v1/src/Box.cpp | "C++" | 0 | 7 | 0 | 3 | 10
/Users/shao/Documents/PlatformIO/Projects/230113-120228-esp32doit-devkit-v1/src/Box.h | "C++" | 0 | 10 | 0 | 6 | 16
/Users/shao/Documents/PlatformIO/Projects/230113-120228-esp32doit-devkit-v1/src/Calculator.cpp | "C++" | 0 | 107 | 10 | 13 | 130
/Users/shao/Documents/PlatformIO/Projects/230113-120228-esp32doit-devkit-v1/src/Calculator.h | "C++" | 0 | 24 | 1 | 8 | 33
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

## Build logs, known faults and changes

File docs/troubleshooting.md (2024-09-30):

# Troubleshooting
## Not turning on

1. Check the power indicator lights: if it's off, then the battery is drained. Charge it.
2. Some models have a protective sticker at the bottom of the microSD card that makes the connection unstable. Removing it will make connections a lot better.

If the lights are on:
1. The microSD card is loose. Gently push the card in until the screen lights up. Or if you want to be sure, connect the SCI-CALC to your computer via a data usb-c cable and open the serial monitor (baud rate 115200). 
2. The OLED screen module is misaligned. Check the pogo pins on the left side. If misaligned, loosen the screws on the top plate holding the module down, and push the module to the left until the pogo pins are touching the pads

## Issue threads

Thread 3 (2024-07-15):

Attempt to play with the WiFi module

Jayatubi, 2024-07-15:
Hi,

I'm very new to the embedded development and I was going to make some practice on this project so I tried some code to make the WiFi module work as:

```c++
#include <WiFi.h>

void setup() {
    ...
    WiFi.mode(WIFI_STA);
    WiFi.begin(ssid, pwd);

    Serial.print("WiFi connecting");

    while (WiFi.status() != WL_CONNECTED)
    {
        Serial.print(".");
        delay(500);
    }

    Serial.println("");
    Serial.print("IP:");
    Serial.println(WiFi.localIP());
    Serial.print("WiFi RSSI:");
    Serial.println(WiFi.RSSI());
}

```

However, when I was going to compile this project I got some errors like:

```
ld: .pio/build/sci_calc_firmware/firmware.elf section `.dram0.bss' will not fit in region `dram0_0_seg'
ld: DRAM segment data does not fit.
ld: DRAM segment data does not fit.
ld: region `dram0_0_seg' overflowed by 2544 bytes
```

How can I address what the issue is? Does that mean the executable is too large?

shaoxiongduan, 2024-07-17:
Would you mind sharing more of your code? I tested the SCI-CALC with the esp32 wifi connection example that comes with the arduino IDE and it works fine. I would recommend testing that first. You can find the example located at File/examples/WiFi/WifiClientConnect.

Jayatubi, 2024-07-18:
Actually I didn't do any thing special. I just clone this repo and add one line in the end of the `init` function in the main.cpp:

```
#include <WiFi.h>

void init() {
    u8g2.begin();
    u8g2.setFontMode(0);
    Serial.begin(115200);
    u8g2.setFont(u8g2_font_profont10_mf);
    u8g2.setFontPosCenter();
    u8g2.setFontMode(1);
    u8g2.enableUTF8Print();

    Serial.begin(115200);
   //first init and check SD card
    if (!SD.begin(4)) {
        rebootEspWithReason("Card Mount Failed");
    }

    uint8_t cardType;
    cardType = SD.cardType();
    if (cardType == CARD_NONE) {
        rebootEspWithReason("No SD_MMC card attached");
    }
    pinMode(36, INPUT);
    initFromFile();
    WiFi.mode(WIFI_STA);  // Just add this
}
```

Then I got the issue while linking: `ld: region `dram0_0_seg' overflowed by 2544 bytes`.

If I remove all the original code and only keep only the WiFi related stuffs it would be fine then but I want to make them to work together.

yangnuozhen, 2024-08-15:
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

I occurred the same problem...

It seems that due to the characteristics of ESP32, the WiFi library always reduces the data memory (DRAM) in ESP32 by a certain size, making it impossible for the heap to allocate the required space on the DRAM of ESP32, causing the problem you encounter.

The only way to solve this problem is to replace a lighter WiFi library, or reduce the DRAM usage of other parts of the code (for example, remove the Bluetooth module and its related functions, Bluetooth will also occupy a large amount of memory space on DRAM. However, if you have experience, you can also adjust the memory allocation strategy of ESP32.

For more information of the heap memory allocation, read this: https://docs.espressif.com/projects/esp-idf/en/v5.3/esp32/api-reference/system/mem_alloc.html

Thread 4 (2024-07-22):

How to install the update for the macropad

Bow3ryList, 2024-07-22:
Hi Shao,

How do I update the SCI-CALC with the fix for the macropad (does is fix the issue with the 7, 8 and 9 keys being swapped with the esc, and the bracket keys)? Is it a case of downloading all the files and putting them onto the SD card using an adaptor or is it just the .bin put the needs to be copied over to the SD in the corresponding folder?

Thanks

Tom

shaoxiongduan, 2024-07-22:
Hello Tom,

You have to download the main.bin file from my github page (the bin files
are located in the sci-calc-code/bin folder) and replace the main.bin in
the microsd card. Once that's done go to the settings page in the sci-calc,
if there is an update from SD option click that, if not then go to the
programs page, select any game in the bin, and wait for the game to load.
Once the game loads you can press esc to go back (the sci-calc freezes for
a moment here, dont worry). And you should be running the newest code! If
you have any problems or discover any bugs please let me know!

-Shao

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

Bow3ryList, 2024-07-22:
Yep, that has fixed the numbers. Thanks

Next question is how do I change the macro customisable keys as I think they are formatted for a different system (maybe for a mac?) . For example, 'copy' launches copilot (windows key +c) on windows 11 and 'paste' launches the clipboard viewer which is 'windows key' and 'v'. Is there a way to edit this?

Thanks in advance for your help

Tom

shaoxiongduan, 2024-07-23:
Currently you have to modify the code to do so, so follow the vscode + platformio "Setting up dev enviroment" guide in the README. Once the code is set, open up the UIMain.cpp file, and you can modify macros there. Below are some of the name of the keys. So for your case, it's KEY_LEFT_GUI for the windows key.
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

sierrax369, 2024-07-24:
Do you have a timeline when you switch to a "textfile-based" Macro solution?

Bow3ryList, 2024-07-29:
> vscode + platformio

Ah, okay - I thought it needed the 'Arduino IDE' to also be installed to allow the code to be modified. It wasn't clear to me what the 'Arduino IDE' section of setting up the developer environment is required for?

Once the UIMain.cpp has been edited, does it again just replace the file the SD card?

shaoxiongduan, 2024-07-29:
The Arduino IDE is another option if you want to develop more programs for the sci-calc. Most of the code for the sci-calc are coded with the vscode+platformio configuration.

To update the code, first save the changes you made in the UIMain.cpp file, and then press upload at the bottom:

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

And also you need to update the main.bin file in the sd card.
First locate the firmware.bin file compiled:
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

Then copy it to the sd-card and rename it to main.bin.
After that, everything should be properly saved and working.

Bow3ryList, 2024-07-29:
Okay, have follow those steps up to 'upload' but I get the following error message once it completes

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

Is that normal, or have I made a mistake copying the cloning the codes files?

Thanks

yangnuozhen, 2024-08-07:
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

Hi Tom,

It seems that you did not specify the upload port during the upload process. Please ensure that SCI-CALC is connected to the computer and that the computer can correctly detect and establish a connection with the port.

To check if the port is correctly connected to the computer, you can follow these steps:

### On Windows

1. **Device Manager**:
   - Right-click on the "This PC" or "Computer" icon and select "Manage".
   - In the opened "Computer Management" window, select "Device Manager" on the left side.
   - Expand the "Ports (COM & LPT)" section, where you should see the connected device and its corresponding port number (e.g., COM3, COM4, etc.).

2. **CMD**:
   - Open Command Prompt (press `Win + R`, type `cmd`, and then press Enter).
   - Enter the following command to view the currently connected serial ports:

     ```cmd
     mode
     ```

### On macOS

1. **Terminal**:
   - Open Terminal (you can find it in "Applications" -> "Utilities").
   - Enter the following command to view the currently connected serial ports:

     ```bash
     ls /dev/tty.*
     ```

   - You should see devices like `/dev/tty.usbserial-xxxx` or `/dev/tty.usbmodemxxxx`.

### On Linux

1. **Terminal**:
   - Open Terminal.
   - Enter the following command to view the currently connected serial ports:

     ```bash
     dmesg | grep tty
     ```

   - You should see devices like `/dev/ttyUSB0` or `/dev/ttyACM0`.

### Using PlatformIO to Check Ports

If you want to check whether the device is correctly recognized by PlatformIO, you can use the following command to list all ports readable by PlatformIO:

```bash
pio device list
```

This will display all currently connected serial devices and their detailed information.

After ensuring the correct connection, try uploading again.

Hope this helps!

Bow3ryList, 2024-08-22:
Thanks for bearing with us on that one Shao - just got around to trying that and it appears to have done the trick and allowed me to edit the marcopad functions so that they are compatible with Windows :)

Closed 2024-09-21.

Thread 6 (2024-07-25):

Any way to disable the power or charging light?

Goose-Dev, 2024-07-25:
When plugged in and charging or powered on there are two bright red lights. Any way to disable them?

shaoxiongduan, 2024-07-26:
Unfortunately the LEDs are all hardwired to light up for debug purposes. If you want to disable them, you can try desoldering them or replacing the resistors that connect to them with one with a larger resistance.

Closed 2024-07-26.

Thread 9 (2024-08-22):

Programming the 'del' key for a hold key function

Bow3ryList, 2024-08-22:
Hi Shao,

Is it possible to program the 'del' key on the macropad so that when the key is held it starts repeatedly pressing the key, similar to how the backpack key works on a keyboard?

Just wondering if there is an easy way to implement it?

Thanks

Tom

yangnuozhen, 2024-08-23:
I added this between https://github.com/shaoxiongduan/sci-calc/blob/8db8b3062902c7a97a66d7f8695507e86526fe55/sci_calc_code/src/UIElements/InputBox.cpp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:

```cpp
if (kb.getRisingEdgeKey() == std::make_pair(4, 3)){
        int curtime = millis();
        bool repeatDelete = false;
        int lastDeleteTime = curtime;
        while (kb.getKey(4, 3).getIsPressed()) {
            delay(20);
            if (millis() - curtime > 1000){
                repeatDelete = true;
            }
            if (repeatDelete && (millis() - lastDeleteTime > 100)){
                Serial.println("deleting str[Repeat]");
                deleteStr();
                u8g2.clearBuffer();
                draw();
                u8g2.sendBuffer();
                lastDeleteTime = millis();
            }
            kb.update();
        }
    }
```

https://github.com/user-attachments/assets/4e8e056a-10e1-43e7-b67c-b17b7dfaf8a6

However, the above code does not fully meet the expected effect. Since the while loop blocks the main loop `loop()`, we have to clear and resend the buffer of u8g2. This results in only the InputBox element being drawn correctly, while other elements disappear.

But I can't think of a better solution at the moment.

Bow3ryList, 2024-08-23:
Nice, that worked for me on the calculator.

I wonder if it is possible to do something similar for the macro pad?

Closed 2024-08-27.

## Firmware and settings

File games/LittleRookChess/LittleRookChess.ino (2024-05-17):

/*

  LittleRookChess.ino
  
  A Simple Chess Engine (ported from U8glib)

  Universal 8bit Graphics Library (https://github.com/olikraus/u8g2/)

  Copyright (c) 2016, olikraus@gmail.com
  All rights reserved.

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
  THIS SOFTWARE IS PROVIDED BY THE COPYRIGHT HOLDERS AND 
  CONTRIBUTORS "AS IS" AND ANY EXPRESS OR IMPLIED WARRANTIES, 
  INCLUDING, BUT NOT LIMITED TO, THE IMPLIED WARRANTIES OF 
  MERCHANTABILITY AND FITNESS FOR A PARTICULAR PURPOSE ARE 
  DISCLAIMED. IN NO EVENT SHALL THE COPYRIGHT HOLDER OR 
  CONTRIBUTORS BE LIABLE FOR ANY DIRECT, INDIRECT, INCIDENTAL, 
  SPECIAL, EXEMPLARY, OR CONSEQUENTIAL DAMAGES (INCLUDING, BUT 
  NOT LIMITED TO, PROCUREMENT OF SUBSTITUTE GOODS OR SERVICES; 
  LOSS OF USE, DATA, OR PROFITS; OR BUSINESS INTERRUPTION) HOWEVER 
  CAUSED AND ON ANY THEORY OF LIABILITY, WHETHER IN CONTRACT, 
  STRICT LIABILITY, OR TORT (INCLUDING NEGLIGENCE OR OTHERWISE) 
  ARISING IN ANY WAY OUT OF THE USE OF THIS SOFTWARE, EVEN IF 
  ADVISED OF THE POSSIBILITY OF SUCH DAMAGE.  

  Current Rule Limitation
    - no minor promotion, only "Queening" of the pawn
    - threefold repetition is not detected (same board situation appears three times)
	Note: Could be implemented, but requires tracking of the complete game
    - Fifty-move rule is not checked (no pawn move, no capture within last 50 moves)
	
  Words
    Ply		a half move
    
  General Links
    http://chessprogramming.wikispaces.com/

  Arduino specific
    http://www.arduino.cc/cgi-bin/yabb2/YaBB.pl?num=1260055596
    
  Prefixes  
    chess_		Generic Chess Application Interface
    ce_		Chess engine, used internally, these function should not be called directly
    cu_		Chess utility function
    stack_		Internal function for stack handling

  Issues
    10.01.2011
      - castling to the right does not move the rook
	  --> done
      - castling to the left: King can only move two squares
	  --> done
      
    11.01.2011	
      Next Steps:
	- replace stack_NextCurrentPos with cu_NextPos, cleanup code according to the loop variable
	    --> done
	- Castling: Need to check for fields under attack
	    --> done
	
	- Check for WIN / LOOSE situation, perhaps call ce_Eval() once on the top-level board setup
	    just after the real move
	- cleanup cu_Move
	    --> almost done
	- add some heuristics to the eval procedure
	- add right side menu
	  --> done
	- clean up chess_ManualMove
	  --> done
	- finish menu (consider is_game_end, undo move)
        - end condition: if KING is under attack and if KING can not move to a field which is under attack...
	      then the game is lost. What will be returned by the Eval procedure? is it -INF?
	    --> finished
	    
	- reduce the use of variable color, all should be reduced to board_orientation and ply&1
	
	- chess_GetNextMarked shoud make use of cu_NextPos
	    --> done
	- chess_ManualMove: again cleanup, solve draw issue (KING is not in check and no legal moves are available)
	    --> done
    22.01.2011
	- simplify eval_t ce_Eval(void)
	- position eval does not work, still moves side pawn :-(
	      maybe because all pieces are considered
	    --> done

    17. June 2016
	U8g2/Arduboy Port
*/

#include <Arduino.h>
#include "Keyboard.h"
#include <U8g2lib.h>

#ifdef U8X8_HAVE_HW_SPI
#include <SPI.h>
#endif
#ifdef U8X8_HAVE_HW_I2C
#include <Wire.h>
#endif

#define SPI_CLK 18
#define SPI_DATA 23
#define SPI_CS 5
#define SPI_DC 16
#define SPI_RESET 17

U8G2_SSD1322_NHD_256X64_F_4W_HW_SPI u8g2(U8G2_R0, SPI_CS, SPI_DC);

Keyboard kb;

void performUpdate(Stream &updateSource, size_t updateSize) {
    if (Update.begin(updateSize)) {      
        size_t written = Update.writeStream(updateSource);
        if (written == updateSize) {
            Serial.println("Written : " + String(written) + " successfully");
        }
        else {
            Serial.println("Written only : " + String(written) + "/" + String(updateSize) + ". Retry?");
        }
        if (Update.end()) {
            Serial.println("OTA done!");
            if (Update.isFinished()) {
                Serial.println("Update successfully completed. Rebooting.");
            }
            else {
                Serial.println("Update not finished? Something went wrong!");
            }
        }
        else {
            Serial.println("Error Occurred. Error #: " + String(Update.getError()));
        }

    }
    else {
        Serial.println("Not enough space to begin OTA");
    }
}

// check given FS for valid update.bin and perform update if available
void updateFromFS(fs::FS &fs, std::string path) {
    u8g2.clearBuffer();
    u8g2.sendBuffer();
    u8g2.drawButtonUTF8(128, 32, U8G2_BTN_HCENTER|U8G2_BTN_BW1, 34,  2,  3, ("writing " + path + " to ROM...").c_str());
    
    u8g2.sendBuffer();

    File updateBin = fs.open(path.c_str());
    if (updateBin) {
        if(updateBin.isDirectory()){
            Serial.println(("Error, " + path + " is not a file").c_str());
            updateBin.close();
            return;
        }

        size_t updateSize = updateBin.size();

        if (updateSize > 0) {
            Serial.println("Try to start update");
            performUpdate(updateBin, updateSize);
        }
        else {
            Serial.println("Error, file is empty");
        }

        updateBin.close();
    
        // whe finished remove the binary from sd card to indicate end of the process
        //fs.remove("/update.bin");      
    }
    else {
        Serial.println("Could not load update.bin from sd root");
    }
}

void rebootEspWithReason(std::string reason) {
    Serial.println(reason.c_str());
    delay(100);
    ESP.restart();
}
/*
  U8glib Example Overview:
    Frame Buffer Examples: clearBuffer/sendBuffer. Fast, but may not work with all Arduino boards because of RAM consumption
    Page Buffer Examples: firstPage/nextPage. Less RAM usage, should work with all Arduino boards.
    U8x8 Text Only Example: No RAM usage, direct communication with display controller. No graphics, 8x8 Text only.
    
  This is a page buffer example.    
*/

void chess_Init(u8g2_t *u8g, uint8_t body_color);

//#define PI_SHIELD


/*=== ARDUBOY Production, Kickstarter Edition ===*/
//U8G2_SSD1306_128X64_NONAME_1_4W_HW_SPI u8g2(U8G2_R0, /* cs=*/ 12, /* dc=*/ 4, /* reset=*/ 6);	// Arduboy (Production, Kickstarter Edition)
void setup(void) {
  Serial.begin(115200);
  //u8g2.begin(/*Select=*/ A0, /*Right/Next=*/ 5, /*Left/Prev=*/ 9, /*Up=*/ 8, /*Down=*/ 10, /*Home/Cancel=*/ A1); // Arduboy DevKit
  //u8g2.begin(/*Select=*/ 7, /*Right/Next=*/ 8, /*Left/Prev=*/ 10, /*Up=*/ U8X8_PIN_NONE, /*Down=*/ U8X8_PIN_NONE, /*Home/Cancel=*/ 9); // Pax Instrument Shield
  Serial.println("start");
  u8g2.begin();
  uint8_t cardType;
  

   // You can uncomment this and build again
   // Serial.println("Update successfull");

   //first init and check SD card
   if (!SD.begin(4)) {
      rebootEspWithReason("Card Mount Failed");
   }

   cardType = SD.cardType();

   if (cardType == CARD_NONE) {
      rebootEspWithReason("No SD_MMC card attached");
   }
  kb.init();
  Serial.println("u8g2 setup done!");
  chess_Init(u8g2.getU8g2(), 1);  /* assuming Arduboy OLED here, so make the body_color be 1 for the white OLED pixel */
  Serial.println("chess setup done!");
}



/* Ignore PROGMEM for now */
#define CHESS_PROGMEM
#define chess_pgm_read(p) (*(p))
#define CHESS_PSTR(s) (s)
#define u8g2_DrawStrP u8g2_DrawStr

/* backward compatibility */
#define u8g2_SetDefaultBackgroundColor(u8g2) \
  u8g2_SetDrawColor(u8g2, 0)
#define u8g2_SetDefaultForegroundColor(u8g2) \
  u8g2_SetDrawColor(u8g2, 1)


/* menu button definitions: mapped to the u8g2 menu events */

#define CHESS_KEY_NONE 0
#define CHESS_KEY_NEXT 1
#define CHESS_KEY_PREV 2
#define CHESS_KEY_SELECT 3
#define CHESS_KEY_BACK 4

/*
SAN identifies each piece by a single upper case letter.  The standard English
values: pawn = "P", knight = "N", bishop = "B", rook = "R", queen = "Q", and
king = "K".
*/

/* numbers for the various pieces */
#define PIECE_NONE	0
#define PIECE_PAWN 	1
#define PIECE_KNIGHT  	2
#define PIECE_BISHOP 	3
#define PIECE_ROOK	4
#define PIECE_QUEEN 	5
#define PIECE_KING		6

/* color definitions */
#define COLOR_WHITE	0
#define COLOR_BLACK	1

/* a mask, which includes COLOR and PIECE number */
#define COLOR_PIECE_MASK 0x01f

#define CP_MARK_MASK 0x20

#define ILLEGAL_POSITION 255

/* This is the build in upper limit of the search stack */
/* This value defines the amount of memory allocated for the search stack */
/* The search depth of this chess engine can never exceed this value */
#define STACK_MAX_SIZE 5

/* chess half move stack: twice the number of undo's, a user can do */ 
#define CHM_USER_SIZE 6

/* the CHM_LIST_SIZE must be larger than the maximum search depth */
/* the overall size of ste half move stack */
#define CHM_LIST_SIZE (STACK_MAX_SIZE+CHM_USER_SIZE+2)

typedef int16_t eval_t;	/* a variable type to store results from the evaluation */ 
//#define EVAL_T_LOST -32768
#define EVAL_T_MIN -32767
#define EVAL_T_MAX 32767
//#define EVAL_T_WIN 32767

/* for maintainance of our own stack: this is the definition of one element on the stack */
struct _stack_element_struct
{
  /* the current source position which is investigated */
  uint8_t current_pos;
  uint8_t current_cp;
  uint8_t current_color;	/* COLOR_WHITE or COLOR_BLACK: must be predefines */
  
  /* the move which belongs to that value, both values are game positions */
  uint8_t best_from_pos;
  uint8_t best_to_pos;
  /* the best value, which has been dicovered so far */
  eval_t best_eval;
};
typedef struct _stack_element_struct stack_element_t;
typedef struct _stack_element_struct *stack_element_p;

/* chess half move history */
struct _chm_struct
{
  uint8_t main_cp;		/* the main piece, which is moved */
  uint8_t main_src;		/* the source position of the main piece */
  uint8_t main_dest; 	/* the destination of the main piece */
  
  uint8_t other_cp;		/* another piece: the captured one, the ROOK in case of castling or PIECE_NONE */
  uint8_t other_src;		/* the delete position of other_cp. Often identical to main_dest except for e.p. and castling */
  uint8_t other_dest;		/* only used for castling: ROOK destination pos */
  
  /* the position of the last pawn, which did a double move forward */
  /* this is required to check en passant conditions */
  /* this array can be indexed by the color of the current player */
  /* this is the condition BEFORE the move was done */
  uint8_t pawn_dbl_move[2];
  
  /* flags for the movement of rook and king; required for castling */
  /* a 1 means: castling is (still) possible */
  /* a 0 means: castling not possible */
  /*  bit 0 left side white */
  /*  bit 1 right side white */
  /*  bit 2 left side black */
  /*  bit 3 right side black */
  /* this is the condition BEFORE the move was done */
  uint8_t castling_possible;   
};

typedef struct _chm_struct chm_t;
typedef struct _chm_struct *chm_p;

/* little rook chess, main structure */
struct _lrc_struct
{  
  /* half-move (ply) counter: Counts the number of half-moves so far. Starts with 0 */
  /* the lowest bit is used to derive the color of the current player */
  /* will be set to zero in chess_SetupBoard() */
  uint8_t ply_count;
  
  /* the half move stack position counter, counts the number of elements in chm_list */
  uint8_t chm_pos;
  
  /* each element contains a colored piece, empty fields have value 0 */
  /* the field with index 0 is black (lower left) */
  uint8_t board[64];	
  /* the position of the last pawn, which did a double move forward */
  /* this is required to check en passant conditions */
  /* this array can be indexed by the color of the current player */
  uint8_t pawn_dbl_move[2]; 
  
  /* flags for the movement of rook and king; required for castling */
  /* a 1 means: castling is (still) possible */
  /* a 0 means: castling not possible */
  /*  bit 0 left side white */
  /*  bit 1 right side white */
  /*  bit 2 left side black */
  /*  bit 3 right side black */
  uint8_t castling_possible; 
  
  /* board orientation */
  /* 0: white is below COLOR_WHITE */
  /* 1: black is below COLOR_BLACK */
  /* bascially, this can be used as a color */
  uint8_t orientation;
  
  /* exchange colors of the pieces */
  /* 0: white has an empty body, use this for bright background color */
  /* 1: black has an empty body, use this for dark backround color */
  uint8_t strike_out_color;
  
  /* 0, when the game is ongoing */
  /* 1, when the game is stopped (lost or draw) */
  uint8_t is_game_end;
  /* the color of the side which lost the game */
  /* this value is only valid, when is_game_end is not 0 */
  /* values 0 and 1 represent WHITE and BLACK, 2 means a draw */
  uint8_t lost_side_color;
  
  
  
  /* checks are executed in ce_LoopRecur */
  /* these checks will put some marks on the board */
  /* this will be used by the interface to find out */
  /* legal moves */
  uint8_t check_src_pos;
  uint8_t check_mode;		/* CHECK_MODE_NONE, CHECK_MODE_MOVEABLE, CHECK_MODE_TARGET_MOVE */
  
  
  /* count of the attacking pieces, indexed by color */
  uint8_t find_piece_cnt[2];

  /* sum of the attacking pieces, indexed by color */
  uint8_t find_piece_weight[2];

  /* points to the current element of the search stack */
  /* this stack is NEVER empty. The value 0 points to the first element of the stack */
  /* actually "curr_depth" represent half-moves (plies) */
  uint8_t curr_depth;
  uint8_t max_depth;
  stack_element_p curr_element;
  
  /* allocated memory for the search stack */
  stack_element_t stack_memory[STACK_MAX_SIZE];

  /* the half move stack, used for move undo and depth search, size is stored in chm_pos */
  chm_t chm_list[CHM_LIST_SIZE];
};
typedef struct _lrc_struct lrc_t;

#define CHECK_MODE_NONE 0
#define CHECK_MODE_MOVEABLE 1
#define CHECK_MODE_TARGET_MOVE 2



/*==============================================================*/
/* global variables */
/*==============================================================*/

lrc_t lrc_obj;
u8g2_t *lrc_u8g;  /* pointer to the C object of u8g2 lib, this is used by the chess engine */


/*==============================================================*/
/* forward declarations */
/*==============================================================*/

/* 
  apply no inline to some of the functions:
  avr-gcc very often inlines functions, however not inline saves a lot of program memory!
  On the other hand there are some really short procedures which should be inlined (like cp_GetColor)
  These procedures are marked static to prevent the generation of the expanded procedure, which
  also saves space.
*/

uint8_t stack_Push(uint8_t color) U8G2_NOINLINE;
void stack_Pop(void) U8G2_NOINLINE;
void stack_InitCurrElement(void) U8G2_NOINLINE;
void stack_Init(uint8_t max) U8G2_NOINLINE;
void stack_SetMove(eval_t val, uint8_t to_pos) U8G2_NOINLINE;
uint8_t cu_NextPos(uint8_t pos) U8G2_NOINLINE;
static uint8_t cu_gpos2bpos(uint8_t gpos);
static uint8_t cp_Construct(uint8_t color, uint8_t piece);
static uint8_t cp_GetPiece(uint8_t cp);
static uint8_t cp_GetColor(uint8_t cp);
uint8_t cp_GetFromBoard(uint8_t pos) U8G2_NOINLINE;
void cp_SetOnBoard(uint8_t pos, uint8_t cp) U8G2_NOINLINE;

void cu_ClearBoard(void) U8G2_NOINLINE;
void chess_SetupBoard(void) U8G2_NOINLINE;
eval_t ce_Eval(void);

void cu_ClearMoveHistory(void) U8G2_NOINLINE;
void cu_ReduceHistoryByFullMove(void) U8G2_NOINLINE;
void cu_UndoHalfMove(void) U8G2_NOINLINE;
chm_p cu_PushHalfMove(void) U8G2_NOINLINE;


void ce_CalculatePositionWeight(uint8_t pos);
uint8_t ce_GetPositionAttackWeight(uint8_t pos, uint8_t color);

void chess_Thinking(void);
void ce_LoopPieces(void);


/*==============================================================*/
/* search stack */
/*==============================================================*/

/* get current element from stack */
struct _stack_element_struct *stack_GetCurrElement(void)
{
  return lrc_obj.curr_element;
}

uint8_t stack_Push(uint8_t color)
{
  if ( lrc_obj.curr_depth == lrc_obj.max_depth )
    return 0;
  lrc_obj.curr_depth++;
  lrc_obj.curr_element = lrc_obj.stack_memory+lrc_obj.curr_depth;
  
  /* change view for the evaluation */
  color ^= 1;
  stack_GetCurrElement()->current_color = color;

  return 1;
}

void stack_Pop(void)
{
  lrc_obj.curr_depth--;
  lrc_obj.curr_element = lrc_obj.stack_memory+lrc_obj.curr_depth;
}

/* reset the current element on the stack */
void stack_InitCurrElement(void)
{
  stack_element_p e = stack_GetCurrElement();
  e->best_eval = EVAL_T_MIN;
  e->best_from_pos = ILLEGAL_POSITION;
  e->best_to_pos = ILLEGAL_POSITION;
}

/* resets the search stack (and the check mode) */
void stack_Init(uint8_t max)
{
  lrc_obj.curr_depth = 0;
  lrc_obj.curr_element = lrc_obj.stack_memory;
  lrc_obj.max_depth = max;
  lrc_obj.check_mode = CHECK_MODE_NONE;
  stack_InitCurrElement();
  stack_GetCurrElement()->current_color = lrc_obj.ply_count;
  stack_GetCurrElement()->current_color &= 1;
}

/* assign evaluation value and store the move, if this is the best move */
/* assumes, that current_pos contains the source position */
void stack_SetMove(eval_t val, uint8_t to_pos)
{
  stack_element_p e = stack_GetCurrElement();
  if ( e->best_eval < val )
  {
    e->best_eval = val;
    e->best_from_pos = e->current_pos;
    e->best_to_pos = to_pos;
  }
}

/* 
  calculate next position on a 0x88 board 
  loop is constructed in this way:
  i = 0;
  do
  {
    ...
    i = cu_NextPos(i);
  } while( i != 0 );

  next pos might be started with an illegal position like 255
*/
uint8_t cu_NextPos(uint8_t pos)
{
  /* calculate next gpos */
  pos++;
  if ( ( pos & 0x08 ) != 0 )
  {
    pos+= 0x10;
    pos&= 0xf0; 
  }
  if ( ( pos & 0x80 ) != 0 )
    pos = 0;
  return pos;
}

uint8_t cu_PrevPos(uint8_t pos)
{
  /* calculate prev gpos */
  pos--;
  if ( ( pos & 0x80 ) != 0 )
    pos = 0x077;
  else if ( ( pos & 0x08 ) != 0 )
  {
    pos &= 0xf0; 
    pos |= 0x07;
  }
  return pos;
}


/*==============================================================*/
/* position transltion */
/*==============================================================*/
/*
  there are two positions
    1. game position (gpos): BCD encoded x-y values
    2. board position (bpos): a number between 0 and 63, only used to access the board.
*/
/*
  gpos:	game position value
  returns:	board position
  note:	does not do any checks
*/
static uint8_t cu_gpos2bpos(uint8_t gpos)
{
  uint8_t bpos = gpos;
  bpos &= 0xf0;
  bpos >>= 1;
  gpos &= 0x0f;
  bpos |= gpos;
  return bpos;
}

#define gpos_IsIllegal(gpos) ((gpos) & 0x088)


/*==============================================================*/
/* colored piece handling */
/*==============================================================*/

#define cp_IsMarked(cp)  ((cp) & CP_MARK_MASK)


/*
  piece: one of PIECE_xxx
  color: COLOR_WHITE or COLOR_BLACK

  returns: A colored piece
*/
static uint8_t cp_Construct(uint8_t color, uint8_t piece)
{
  color <<= 4;
  color |= piece;
  return color;
}

/* inline is better than a macro */
static uint8_t cp_GetPiece(uint8_t cp)
{
  cp &= 0x0f;
  return cp;
}

/*
  we could use a macro:
  #define cp_GetColor(cp)	(((cp) >> 4)&1)
  however, inlined functions are sometimes much better
*/
static uint8_t cp_GetColor(uint8_t cp)
{
  cp >>= 4;
  cp &= 1;
  return cp;
}

/*
  pos: game position
  returns the colored piece at the given position
*/
uint8_t cp_GetFromBoard(uint8_t pos)
{
  return lrc_obj.board[cu_gpos2bpos(pos)];
}

/*
  pos: game position
  cp: colored piece
*/
void cp_SetOnBoard(uint8_t pos, uint8_t cp)
{
  /*printf("cp_SetOnBoard gpos:%02x cp:%02x\n", pos, cp);*/
  lrc_obj.board[cu_gpos2bpos(pos)] = cp;
}

/*==============================================================*/
/* global board access */
/*==============================================================*/

void cu_ClearBoard(void)
{
  uint8_t i;
  /* clear the board */
  for( i = 0; i < 64; i++ )
    lrc_obj.board[i] = PIECE_NONE;
  
  lrc_obj.ply_count = 0;
  lrc_obj.orientation = COLOR_WHITE;
  
  lrc_obj.pawn_dbl_move[0] = ILLEGAL_POSITION;
  lrc_obj.pawn_dbl_move[1] = ILLEGAL_POSITION;
  
  lrc_obj.castling_possible = 0x0f;
  
  lrc_obj.is_game_end = 0;
  lrc_obj.lost_side_color = 0;

  /* clear half move history */
  cu_ClearMoveHistory();

}

/*
  test setup
  white wins in one move
*/
void chess_SetupBoardTest01(void)
{
  cu_ClearBoard();
  lrc_obj.board[7+7*8] = cp_Construct(COLOR_BLACK, PIECE_KING);
  lrc_obj.board[7+5*8] = cp_Construct(COLOR_WHITE, PIECE_PAWN);
  lrc_obj.board[3] = cp_Construct(COLOR_WHITE, PIECE_KING);
  lrc_obj.board[0+7*8] = cp_Construct(COLOR_BLACK, PIECE_ROOK);
  lrc_obj.board[6] = cp_Construct(COLOR_WHITE, PIECE_QUEEN);
}
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
void loop(void) {
  static uint8_t keycode = 0;
  std::pair <int, int> p = std::make_pair(0, 0);
  
  //Serial.println("hiefjoejfofejofjie");
  u8g2.firstPage();
  do {
    chess_Draw();
  } while ( u8g2.nextPage() );

  
  kb.update();
  if (kb.getRisingEdgeKey() == std::make_pair(3, 1)) {
    keycode = CHESS_KEY_NEXT;
    Serial.println("nxt");
  }else if (kb.getRisingEdgeKey() == std::make_pair(1, 1)){
    keycode = CHESS_KEY_PREV;
    Serial.println("prev");    
  }else if (kb.getRisingEdgeKey() == std::make_pair(2, 4)){
    keycode = CHESS_KEY_SELECT;
    Serial.println("select");
  }else if (kb.getRisingEdgeKey() == std::make_pair(2, 5)) {
    keycode = CHESS_KEY_BACK;   
    Serial.println("back"); 
  }else{
    Serial.println("none");
    keycode = 0;   
  }     
  //if ( keycode == U8X8_MSG_GPIO_MENU_HOME )
  //  keycode = CHESS_KEY_SELECT;
      
  chess_Step(keycode);
  keycode = 0;
  delay(1);
  if (kb.getRisingEdgeKey() == std::make_pair(0, 0)) {
        Serial.println("uploading new software");
        updateFromFS(SD, "/main.bin");
        rebootEspWithReason("main uploaded!!");
  }
}

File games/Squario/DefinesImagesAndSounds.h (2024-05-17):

#ifndef DEFINESIMAGESANDSOUNDS_h
#define DEFINESIMAGESANDSOUNDS_h
#include <Arduboy2.h>

#define FPSDELAY      1000/30
#define BUTTONCD      200
#define GameSeeds     4
#define TileSize      8
#define MinLevelWidth 12

#define RoomFeatures  3
#define RoomWidth     16
#define RoomHeight    16
#define RoomBytes     (RoomHeight/8) * RoomWidth
#define MapRooms      3
#define MapObjects    30
#define SpriteCap     10

#define POINTSMushroom  100
#define POINTSKill      20

PROGMEM const uint8_t gameover [] = {
0xff, 0x80, 0x0, 0x3f, 0xc3, 0xfc, 0x7, 0xf8, 0x0, 0x80, 0xff, 0xff, 0xe0, 0x42, 0x7, 0xfc, 0xf, 0xf0, 0x80, 0x83, 0x0, 0x20, 0x42, 0x4, 0x4c, 0x8, 0x10, 0x80, 0x83, 0x0, 0x24, 0x42, 0x4, 0x4c, 0x88, 0x10, 0x8f, 0xf3, 0x0, 0x24, 0x42, 0x64, 0x4c, 0x88, 0x10, 0x89, 0x3, 0x23, 0x20, 0x42, 0x64, 0x4c, 0x9, 0x90, 0x89, 0x3, 0x23, 0x20, 0x42, 0x64, 0x4c, 0x9, 0x90, 0x89, 0x3, 0x23, 0x20, 0x42, 0x64, 0x4c, 0x9, 0xf0, 0x89, 0x13, 0x23, 0x21, 0xc2, 0x64, 0x4c, 0x39, 0x0, 0x89, 0x13, 0x23, 0x27, 0xc2, 0x4, 0xc, 0xf9, 0x0, 0x81, 0x3, 0x23, 0x20, 0x42, 0x4, 0xc, 0x9, 0x0, 0x81, 0x3, 0x23, 0x20, 0x42, 0x6, 0xc, 0x9, 0x0, 0xff, 0xff, 0xff, 0xff, 0xc3, 0xfd, 0xf7, 0xff, 0x0, 0x0, 0x0, 0x0, 0x0, 0x0, 0x0, 0x0, 0x0, 0x0
};

enum SpriteDataLayout {
  SpriteWidth = 0,
  SpriteHeight,
  SpriteMaxFrame,
  SpriteCyclesPerFrame,
  SpriteFlags,
  SpriteSpeed,
  SpriteIntelligence,
  SpriteMasks,
  SpriteImageData
};

PROGMEM const uint8_t SmallSquarioSprite[] {
  8, 8, 1, 1,// Width, Height, # of Frames, Cycles per Frame
  0, 0, 0,    // Flags, Speed, AI Setting
  1,          // Number of masks
  0b00000000, // Frame 1 Data
  0b00111110,
  0b11100010,
  0b00100010,
  0b11100010,
  0b00100010,
  0b00111110,
  0b00000000,

  0b00000000, // Frame 1 Mask
  0b10111110,
  0b11111110,
  0b00111110,
  0b11111110,
  0b00111110,
  0b10111110,
  0b00000000,

};
PROGMEM const uint8_t BigSquarioSprite[] {
  8, 16, 1, 1, // Width, Height, # of Frames, Cycles per Frame
  0, 0, 0,     // Flags, Speed, AI Setting
  1,          // Number of masks
  0b11111110, // Frame 1 data
  0b00000010,
  0b00000010,
  0b00000010,
  0b00000010,
  0b00000010,
  0b00000010,
  0b11111110,
  0b00011111,
  0b00010000,
  0b11110000,
  0b00010000,
  0b11110000,
  0b00010000,
  0b00010000,
  0b00011111,
  
  0b11111110, // Frame 1 mask
  0b11111110, 
  0b11111110, 
  0b11111110, 
  0b11111110, 
  0b11111110, 
  0b11111110, 
  0b11111110, 
  0b10011111,
  0b00011111,
  0b11111111,
  0b00011111,
  0b11111111,
  0b00011111,
  0b00011111,
  0b10011111
};
PROGMEM const uint8_t TriangleoSprite[] {
  8, 8, 1, 1, // Width, Height, # of Frames, Cycles per Frame
  0b10,       // Flags
  1, 0b11,    // Speed, AI Setting
  1,          // Number of masks
  0b01000000, // Frame 1 data
  0b01110000,
  0b11001100,
  0b01000011,
  0b11000010,
  0b01001100,
  0b01110000,
  0b01000000,
  
  0b00000000, // Frame 1 mask
  0b00111000,
  0b11111110,
  0b00111111,
  0b11111111,
  0b00111110,
  0b00111000,
  0b00000000
};
PROGMEM const uint8_t StarmanoSprite[] {
  8, 8, 1, 1, // Width, Height, # of Frames, Cycles per Frame
  0b10,       // Flags
  2, 0b1111,  // Speed, AI Setting
  1,          // Number of masks
  0b10000100, // Frame 1 data
  0b11101100,
  0b01111100,
  0b00111111,
  0b00111111,
  0b01111100,
  0b11101100,
  0b10000100,
  
  0b10000100, // Frame 1 Mask
  0b11101100,
  0b01111100,
  0b00111111,
  0b00111111,
  0b01111100,
  0b11101100,
  0b10000100,

};
PROGMEM const uint8_t SmileoSprite[] {
  8, 8, 1, 1, // Width, Height, # of Frames, Cycles per Frame
  0b10,       // Flags
  2, 0b1,     // Speed, AI Setting
  1,          // Number of masks
  0b00111100, // Frame 1 data
  0b01000010,
  0b10000001,
  0b10101001,
  0b10100001,
  0b10101001,
  0b01000010,
  0b00111100,
  
  0b00111100, // Mask 1 data
  0b01111110,
  0b11111111,
  0b11111111,
  0b11111111,
  0b11111111,
  0b01111110,
  0b00111100

};
PROGMEM const uint8_t MushroomSprite[] {
  8, 8, 1, 1, // Width, Height, # of Frames, Cycles per Frame
  0b10,       // Flags
  1, 0b1,     // Speed, AI Setting
  1,          // Number of masks
  0b00011000, // Frame 1 data
  0b00100100,
  0b11101010,
  0b10100001,
  0b10101001,
  0b11110010,
  0b00100100,
  0b00011000,
  
  0b00011000, // Frame 1 mask
  0b00111100,
  0b11111110,
  0b11111111,
  0b11111111,
  0b11111110,
  0b00111100,
  0b00011000
};
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

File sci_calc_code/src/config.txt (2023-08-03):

MACROPAD:
    layout1:
        ESC   / * -         CMD+A CMD+R
        7     8 9 +
        4     5 6 ^
        1     2 3 ENTER
        SHIFT 0 . BACKSPACE 8     8

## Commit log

2023-01-29 pcbs(missing pulldown resistors)
    [BOM_PCB14_2022-12-072.csv, PickAndPlace_PCB14_2022-12-07.csv]
2023-02-01 added a broken clock
    [main.cpp]
2023-02-04 current finished pcb
2023-05-11 fixed the bug in the menu
    fixed the bug in the menu where when you move your cursor past the limit of the max numbers of menu items displayed on one window, the program would crash
    also fixed the checkbox element
    [Menu.cpp]
2024-05-05 Refactored repo
    Made everything much more cleaner
    [config.txt]
2024-05-05 refactor 2
    [config.txt, diff.csv, diff.txt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]
2024-06-12 Fixed Syntax checker bug
    Checksyntax returns false when there is a token with more than one char in the string expression. Fixed.
    [Menu.cpp, main.cpp]
2024-07-23 Missing RESET pin in screen constrcutor
2024-08-07 fix: cursor isn't clear at Menu::clear()
    [Menu.cpp]
2024-08-08 fix: RPN SWITCH shoudn't be inputted
2024-08-24 feat(InputBox): add continuous delete feature on long press of del key
    - Implemented functionality to trigger continuous deletion when the delete key (del) is pressed and held.
    - Added logic to check the duration of the key press and initiate repeated deletions after a specified time threshold.
    - Ensured that deletions occur at regular intervals when the key is held down.
    Code changes:
    - Introduced `delPressedTime`, `repeatDelete`, and `lastDeleteTime` as global variables to manage the timing and state of the delete key press.
    - Used `millis()` to measure the duration of the key press and control the repeated deletion action.
2024-09-30 Added PCB and 3d files
    [BOM_PCB16_1_2024-09-30.xlsx, Part Studio 1 - Base Plate.step, Part Studio 1 - Top Plate.step]
2026-02-18 update BOM file
